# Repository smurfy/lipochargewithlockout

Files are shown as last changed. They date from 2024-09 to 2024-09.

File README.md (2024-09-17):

# LiPo/Ion charger with 3V output lockout

Project was born due to an issue with RAK 4631 baseboard solar charger and battery input.
Low battery/charge charge causes brownout and the RAK 4631 needs manual intervention.
In a solar meshtastic node on a mountain thats not convenient.

On meshtastics discourse michimartini came up with a small board to remedy the issue.
Thread: https://meshtastic.discourse.group/t/rak-4631-solar-repeater/7694

## Changelog and short description

### rev1.0

Original board by michimartini supports 450ma charging current.
Not all parts are available at jlcpcb at time of writing but pcb could be built there and parts sourced and assembled manually.

### rev2.0

Adapted for different charge chip, which supports 500ma but also needs resistor for setting it.

* Increased max charge current to 500ma
* switched MCP73811T-420I-OT to MCP73812T-420I-OT for better compatibility
* specified MCP120-xxxxTT as MCP120T-315I/TT

### rev3.0

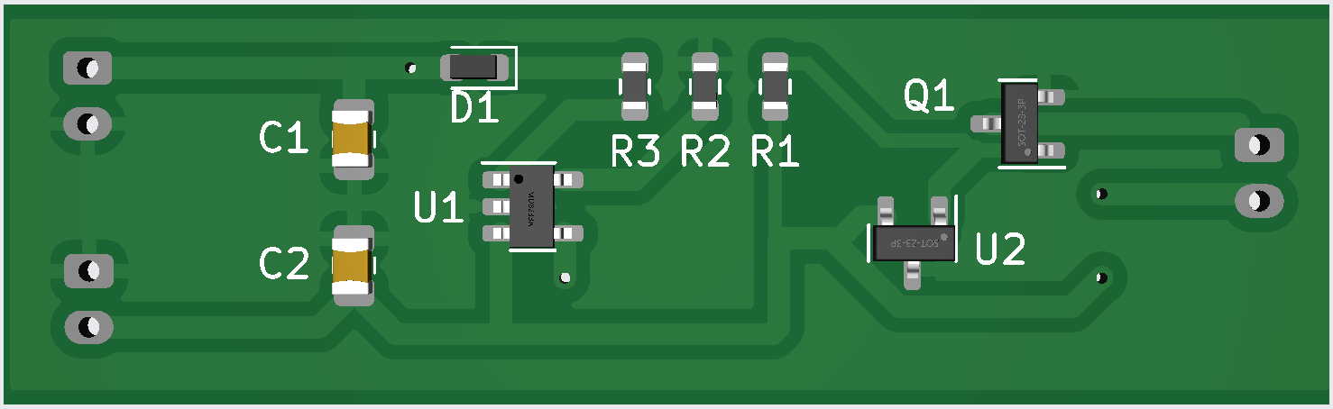
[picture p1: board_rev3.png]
Board rev3


Switched charge chip again, since i did not like the sound of the charging logic of MCP7381/2 especially related to overcharging/continue charging.
This switch also adds support for a charging led, while not really needed for our use case, its nice to have in testing.

* switched MCP73812T-420I-OT to MCP73831T-2DCI-OT since automatic recharge should work better there
* added charge led

### ref4.0 planning stage

Possible improvements for rev3.0 in the future

* add usb connector for easy charging if solar/jst input is not connected
* adding via's or something for temperature of chargechip, since this is mentioned in datasheet
* switch to CN3065 as charging chip (1000ma, temperature sensing, charged led...)
* add INA219 for solar input measurement (with connector to use sensor port/wires)
* add complete baseboard for RAK4631 (using the cpu port connector)

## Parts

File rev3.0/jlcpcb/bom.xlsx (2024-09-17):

Comment | Designator | Footprint | JLCPCB Part #（optional）
4.7uF | C1,C2 | C_0805_2012Metric | C1779
BSS123 | Q1 | SOT-23 | C18198442
MCP120T-315I/TT | U2 | SOT-23 | C461581
270Ω | R1 | R_0603_1608Metric | C22966
MCP73831T-2DCI/OT | U1 | SOT-23-5 | C625597
2KΩ | R2 | R_0603_1608Metric | C22975
LED_Small | D1 | LED_0603_1608Metric | C2286
470Ω | R3 | R_0603_1608Metric | C23179

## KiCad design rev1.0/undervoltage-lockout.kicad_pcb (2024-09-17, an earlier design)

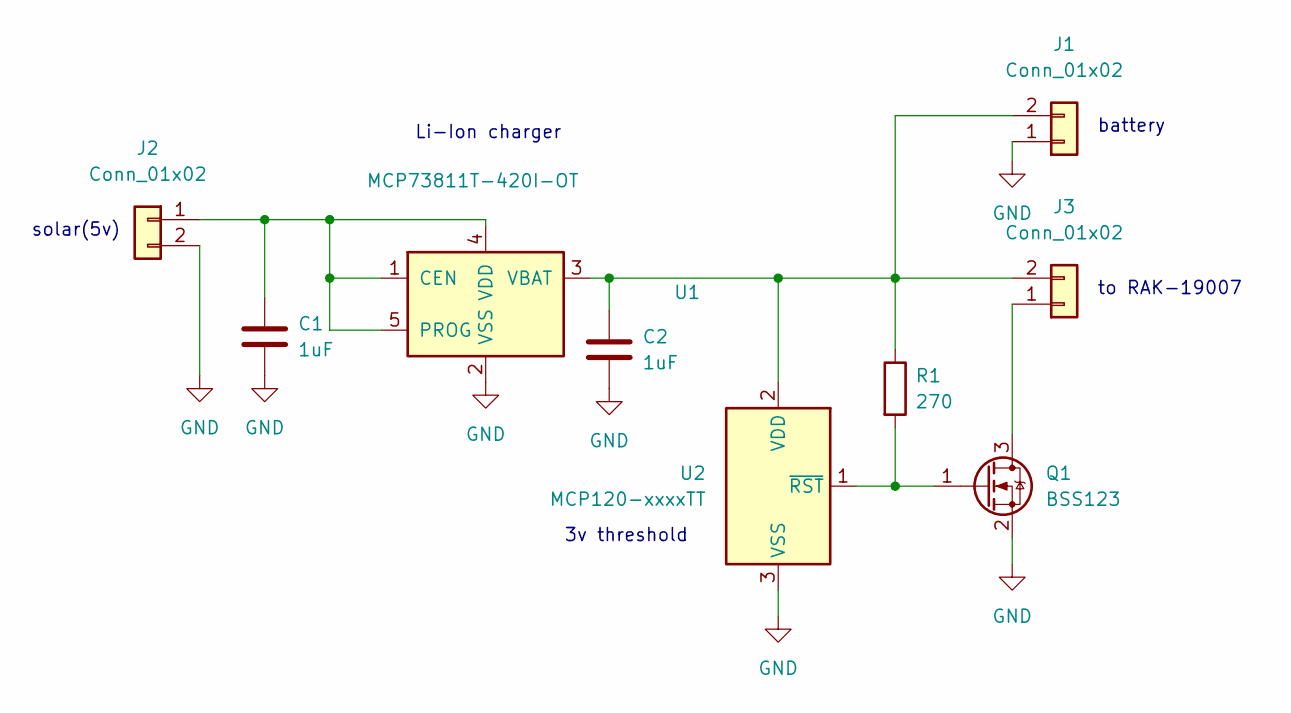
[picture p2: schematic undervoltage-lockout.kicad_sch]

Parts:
C1, C2: 1uF; C_0805_2012Metric
J1, J2, J3: Conn_01x02; JST_PH_B2B-PH-K_1x02_P2.00mm_Vertical
Q1: BSS123; SOT-23
R1: 270; R_0603_1608Metric
U1: MCP73811T-420I-OT; SOT-23-5
U2: MCP120-xxxxTT; SOT-23

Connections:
GND: C1.2, C2.2, J1.1, J2.2, Q1.2 (S), U1.2 (VSS), U2.3 (VSS)
unnamed: C1.1, J2.1, U1.1 (CEN), U1.4 (VDD), U1.5 (PROG)
unnamed: C2.1, J1.2, J3.2, R1.1, U1.3 (VBAT), U2.2 (VDD)
unnamed: J3.1, Q1.3 (D)
unnamed: Q1.1 (G), R1.2, U2.1 (~RST)

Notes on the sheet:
Li-Ion charger
to RAK-19007
3v threshold
battery
solar(5v)

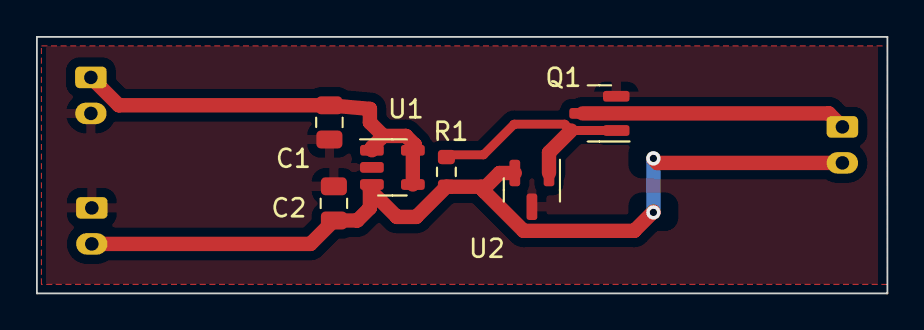
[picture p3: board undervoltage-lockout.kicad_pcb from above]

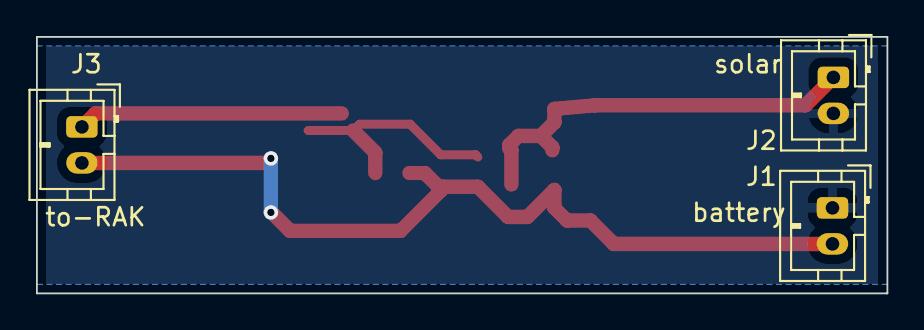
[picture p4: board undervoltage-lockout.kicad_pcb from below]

Board: 2 copper layers, 47.2 x 14.2 mm, 9 parts (3 on the bottom side), 5 nets.

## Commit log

2024-09-17 chore: added original design by michimartini
    [undervoltage-lockout.kicad_pcb, undervoltage-lockout.kicad_sch]
2024-09-17 chore: added rev2.0
    [bom.xlsx, undervoltage-lockout.kicad_pcb, undervoltage-lockout.kicad_sch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]
2024-09-17 chore: added rev3.0
    [bom.xlsx, undervoltage-lockout.kicad_pcb, undervoltage-lockout.kicad_sch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]
